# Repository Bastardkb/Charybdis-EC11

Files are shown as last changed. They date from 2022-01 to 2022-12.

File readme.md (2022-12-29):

# Charybdis EC11 PCB

EC11 PCB to be used in place of the trackball in the Charybdis keyboard.

`REV 1.2` is tested and working.

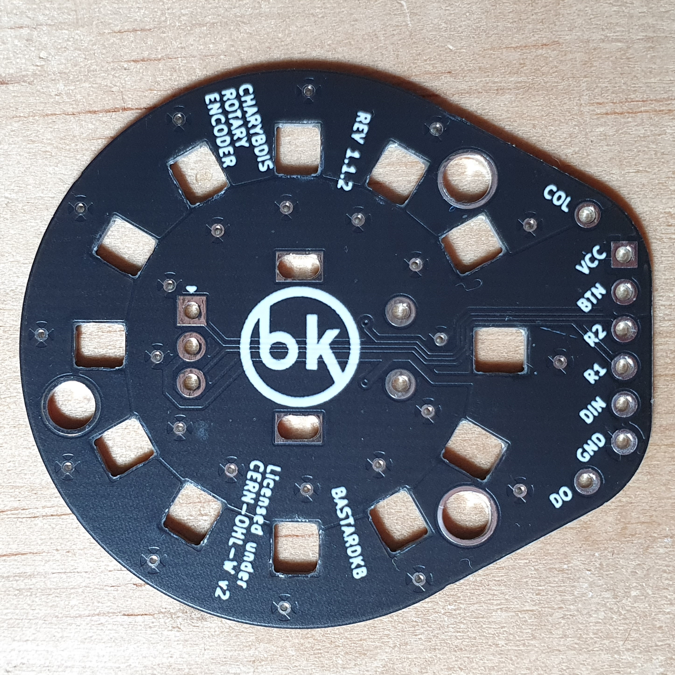
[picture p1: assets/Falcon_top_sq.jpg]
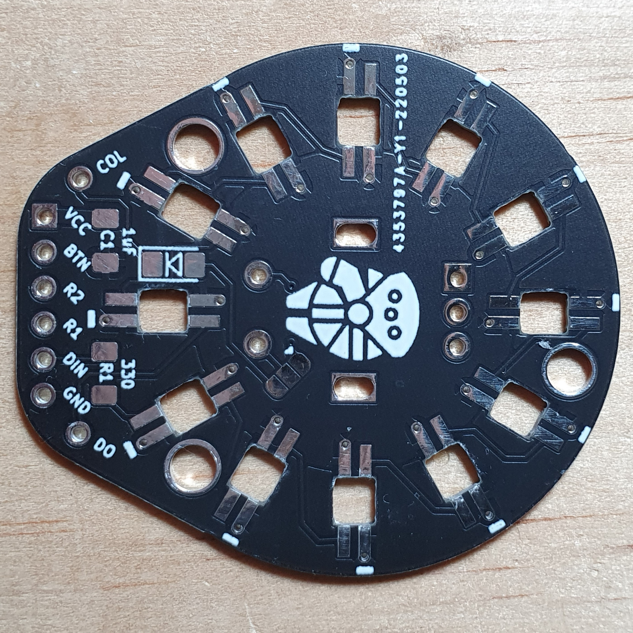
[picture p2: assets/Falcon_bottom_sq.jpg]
 

## EC11 Encoder
R1 and R2 pins are used for the encoder rotation pulses, these should be connected to unused pins on the microcontroller. The MOSI/MISO/SCLK/CS will be the most convenient - any two of these can be used.

For normal configuration of the pushbutton function with the Charybdis:
 - Bridge the 2 unmarked pads on the solder jumper
 - install a SOD-123 diode in the marked footprint
 - connect Col to a column and BTN to a row that corresponds with the missing thumb key matrix position

If your keyboard uses direct pin you will need to bridge the middle pad on the solder jumper with the marked pad. BTN should then be connected to a free GPIO pin on your microcontroller.

## LEDs
LEDs are optional. If not being used, VCC, GND, DIN, and DO can be ignored.

Otherwise:
- Install the capacitor and resistor on the marked footprints
- VCC and GND can be connected to wherever is the most convenient
- DIN and DO should be connected as part of the existing LED chain on the half - the suggested way to do this is to connect the DO from the PCB plate to the EC11 adapter DIN (instead of the thumb cluster), and the thumb cluster pcb DIN to the EC11 adapter DO

## Misc. Note
It should be possible to connect the adapter directly to the 6 pins of the trackball pin header on the shield for better aesthetics and modularity. However this would need custom matrix scanning code - to mix direct pin and switch matrix scanning, as well as a custom RGB LED driver to allow a second `RGB_DI` pin to be defined

## Parts you will need
### For every build

| Part name | Amount | Format  |
| --- | --- | --- |
| Diode, 1N4148 | 1 | SOD-123 |
| EC11 Rotary encoder | 1 | |
| Rotary encoder PCB* | 1 | |

*order the PCB using the latest *gerbers.zip from here: [Releases](https://github.com/Bastardkb/Charybdis-EC11/releases)

### Optional for LED functionality
| Part name | Amount per board | Format | Value  |
| --- | --- | --- | --- |
| SK6812-MINI-E | 12 | | |
| Capacitor | 1 | 1206 | 1uF |
| Resistor | 1 | 1206 | 330ohm |

## Knob
The knob work on the 20mm tall and 6mm diameter knurled stem.

Licensed under CERN-OHL-W v2.

Copyright Quentin Lebastard 2022.

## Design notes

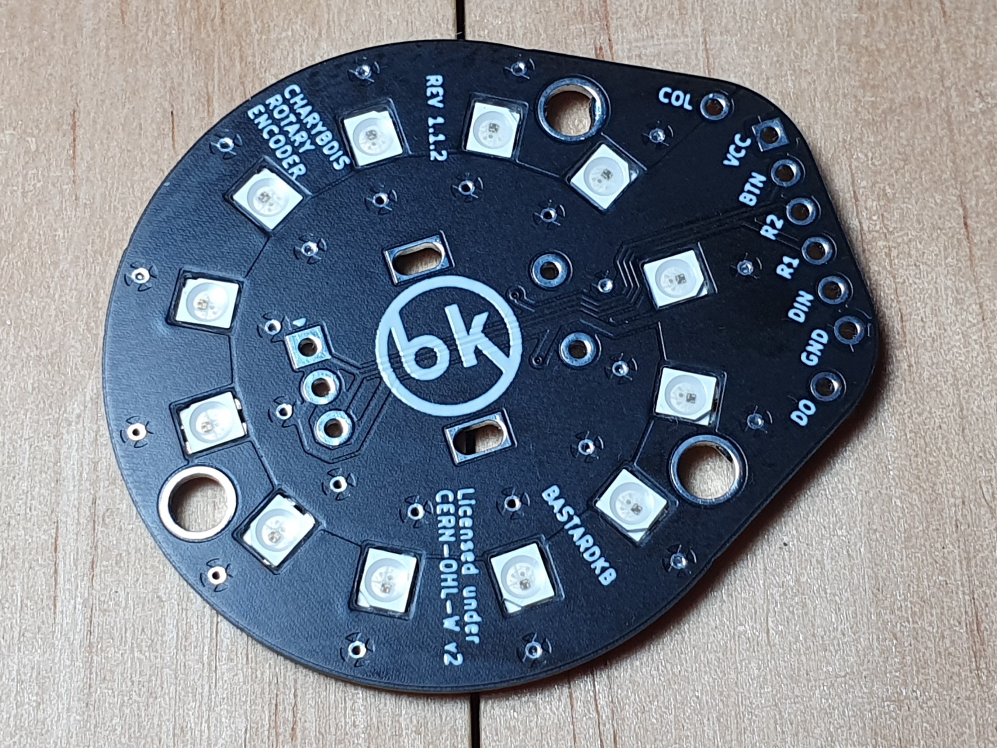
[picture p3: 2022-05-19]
assets/Falcon_top.jpg

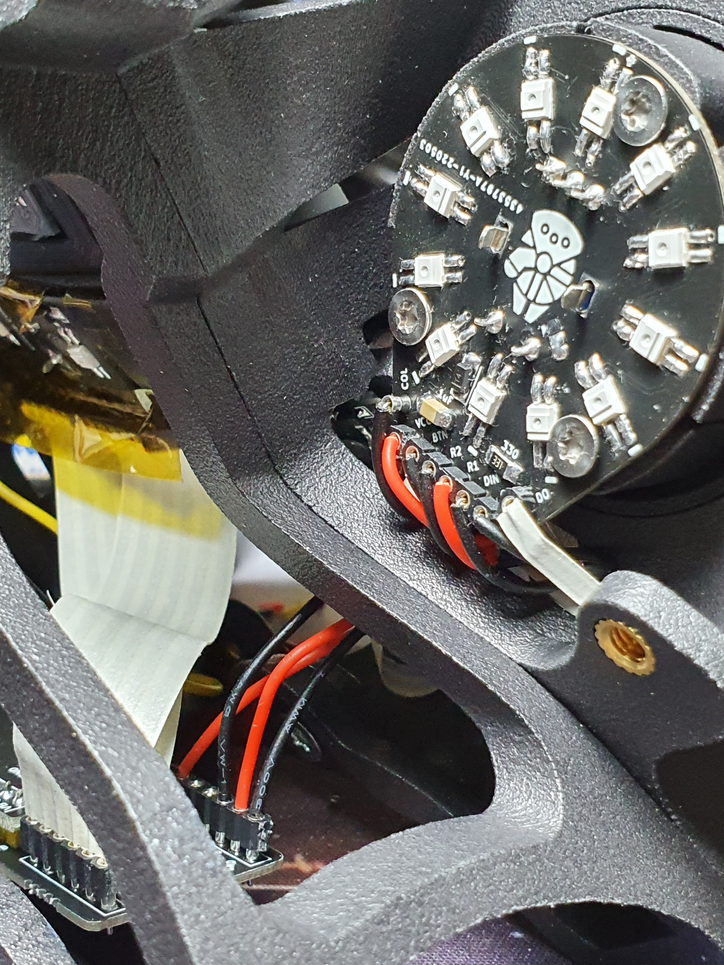
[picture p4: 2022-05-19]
assets/rough_connection_example.jpg

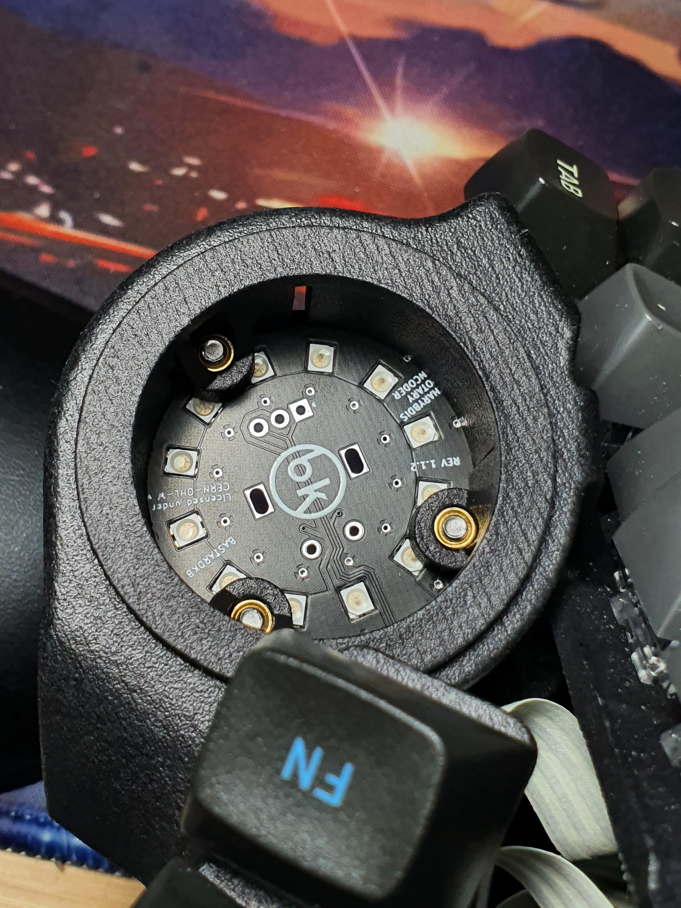
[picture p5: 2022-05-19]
assets/Partial_fit_example.jpg

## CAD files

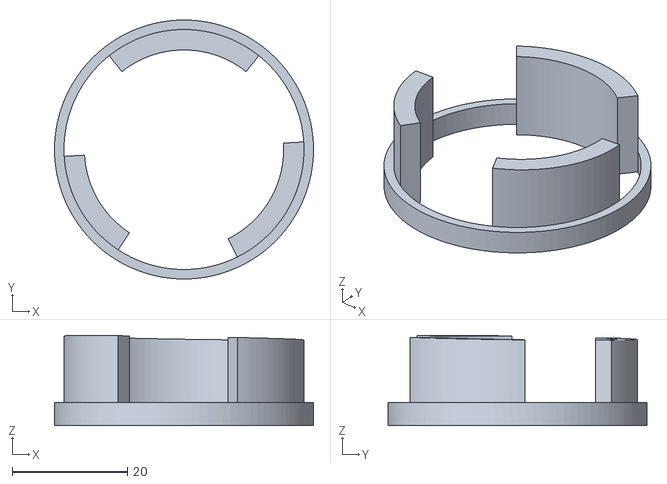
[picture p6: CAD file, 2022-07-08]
mechanical/bottom v7.stl
45.0 x 45.0 x 15.7

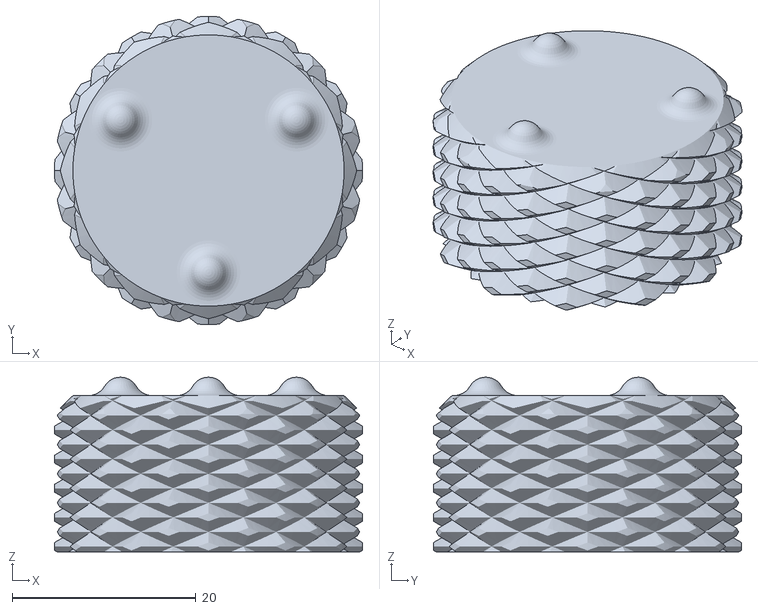
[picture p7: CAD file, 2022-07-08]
mechanical/Knob v5.stl
33.5 x 33.5 x 19.0

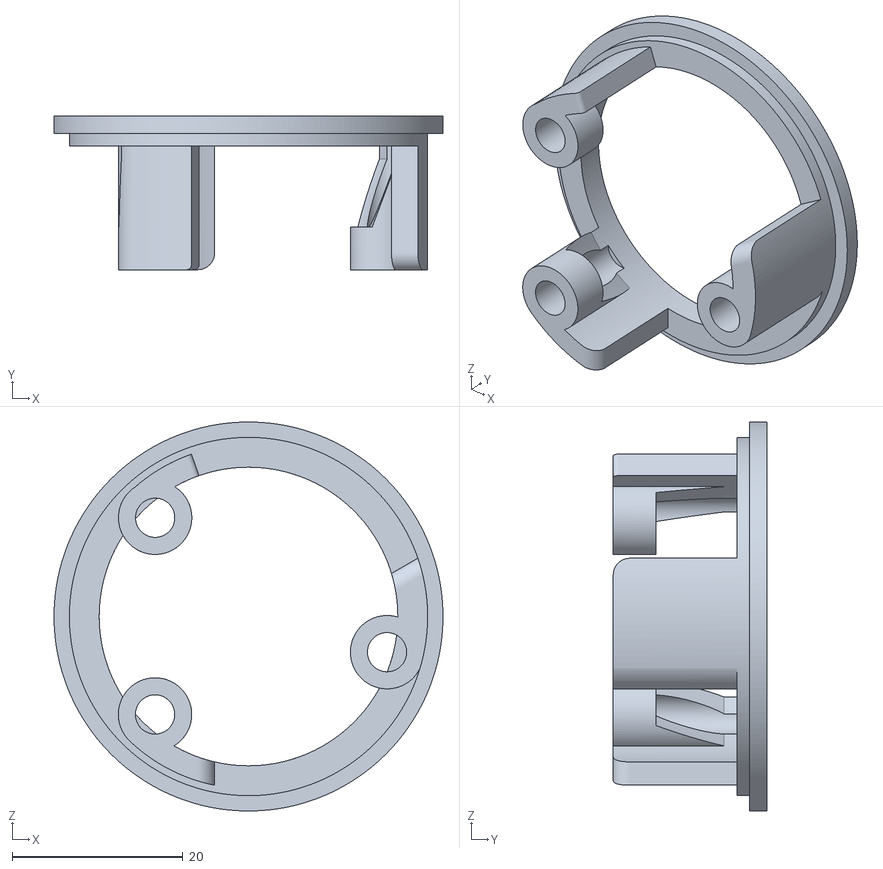
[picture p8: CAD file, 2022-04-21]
mechanical/top.stl
45.6 x 18.0 x 45.6

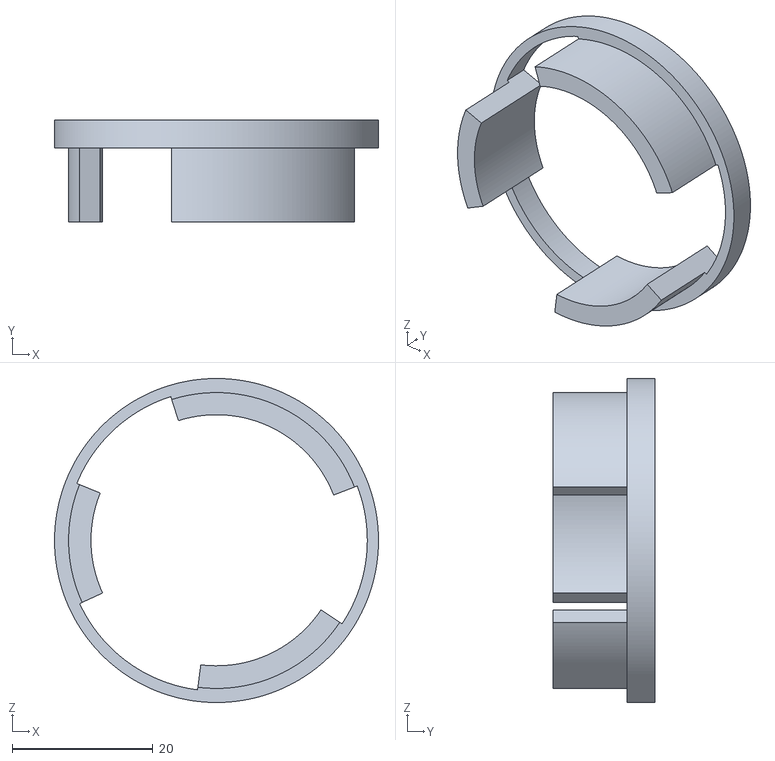
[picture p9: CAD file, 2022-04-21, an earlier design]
mechanical/bottom.stl
46.0 x 14.5 x 46.0

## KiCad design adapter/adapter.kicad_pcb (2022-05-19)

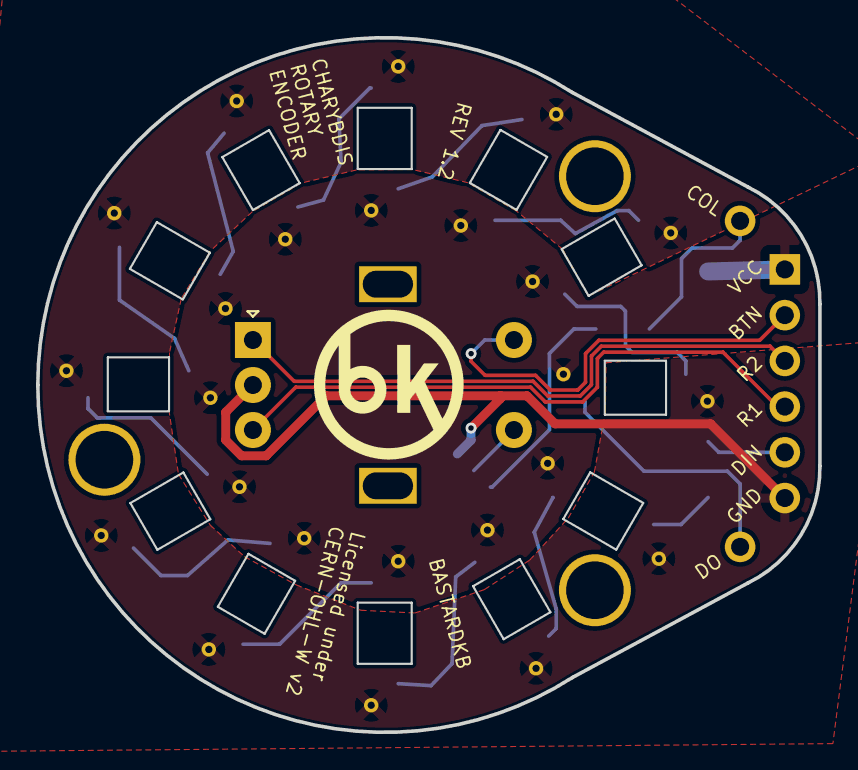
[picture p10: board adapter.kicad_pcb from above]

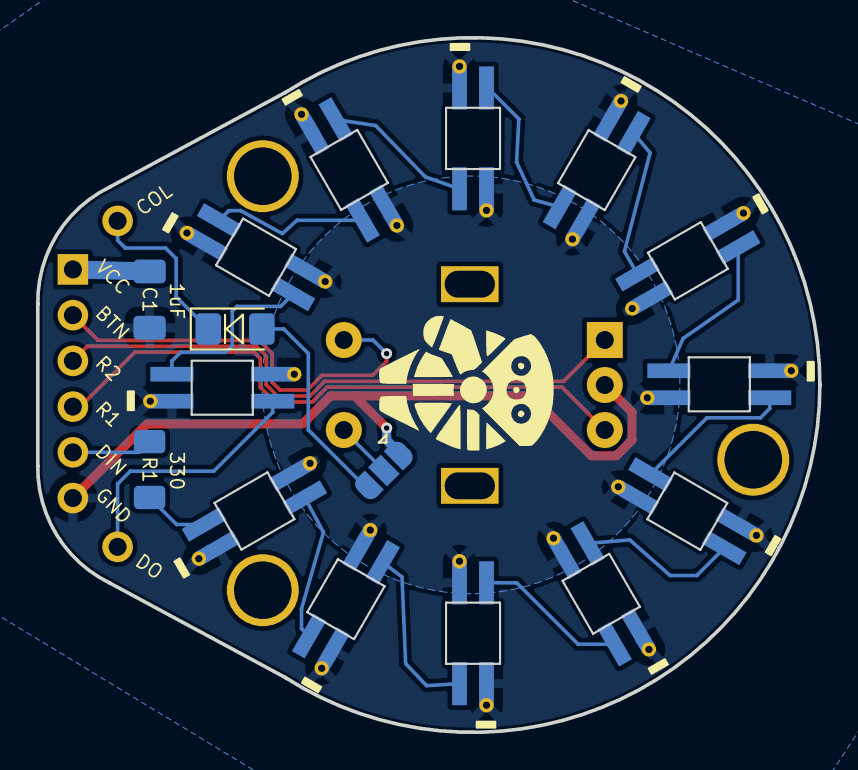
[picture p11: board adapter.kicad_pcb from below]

Board: 2 copper layers, 43.5 x 38.6 mm, 20 parts (16 on the bottom side), 22 nets.

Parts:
C1: 1u; C_1206_3216Metric_Pad1.33x1.80mm_HandSolder
D1, D2, D3, D4, D5, D6, D7, D8, D9, D10, D11, D12: SK6812MINI; YS-SK6812MINI-E
Dcol1: 1N4148W; D_1206_3216Metric_Pad1.42x1.75mm_HandSolder
J1: Conn_01x06_Female; 6_PinHeader
J2, J5: Conn_01x01_Female; 1_PinHeader
JP1: SolderJumper_3_Open; SolderJumper-3_P1.3mm_Open_RoundedPad1.0x1.5mm
R1: R; R_1206_3216Metric_Pad1.30x1.75mm_HandSolder
SW1: RotaryEncoder_Switch; RotaryEncoder_Alps_EC11E-Switch_Vertical_H20mm

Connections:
Col: Dcol1.1 (K), J2.1
DIN: J1.5, R1.2
DOUT: D12.1 (DOUT), J5.1
Gnd: C1.2, D1.2 (VSS), D2.2 (VSS), D3.2 (VSS), D4.2 (VSS), D5.2 (VSS), D6.2 (VSS), D7.2 (VSS), D8.2 (VSS), D9.2 (VSS), D10.2 (VSS), D11.2 (VSS), D12.2 (VSS), J1.6, JP1.1 (A), SW1.C
unnamed: D1.1 (DOUT), D2.3 (DIN)
unnamed: D1.3 (DIN), R1.1
unnamed: D2.1 (DOUT), D3.3 (DIN)
unnamed: D3.1 (DOUT), D4.3 (DIN)
unnamed: D4.1 (DOUT), D5.3 (DIN)
unnamed: D5.1 (DOUT), D6.3 (DIN)
unnamed: D6.1 (DOUT), D7.3 (DIN)
unnamed: D7.1 (DOUT), D8.3 (DIN)
unnamed: D8.1 (DOUT), D9.3 (DIN)
unnamed: D10.1 (DOUT), D11.3 (DIN)
unnamed: D9.1 (DOUT), D10.3 (DIN)
unnamed: D11.1 (DOUT), D12.3 (DIN)
unnamed: Dcol1.2 (A), JP1.3 (B)
unnamed: JP1.2 (C), SW1.S1
Vcc: C1.1, D1.4 (VDD), D2.4 (VDD), D3.4 (VDD), D4.4 (VDD), D5.4 (VDD), D6.4 (VDD), D7.4 (VDD), D8.4 (VDD), D9.4 (VDD), D10.4 (VDD), D11.4 (VDD), D12.4 (VDD), J1.1
button: J1.2, SW1.S2
r1: J1.4, SW1.B
r2: J1.3, SW1.A

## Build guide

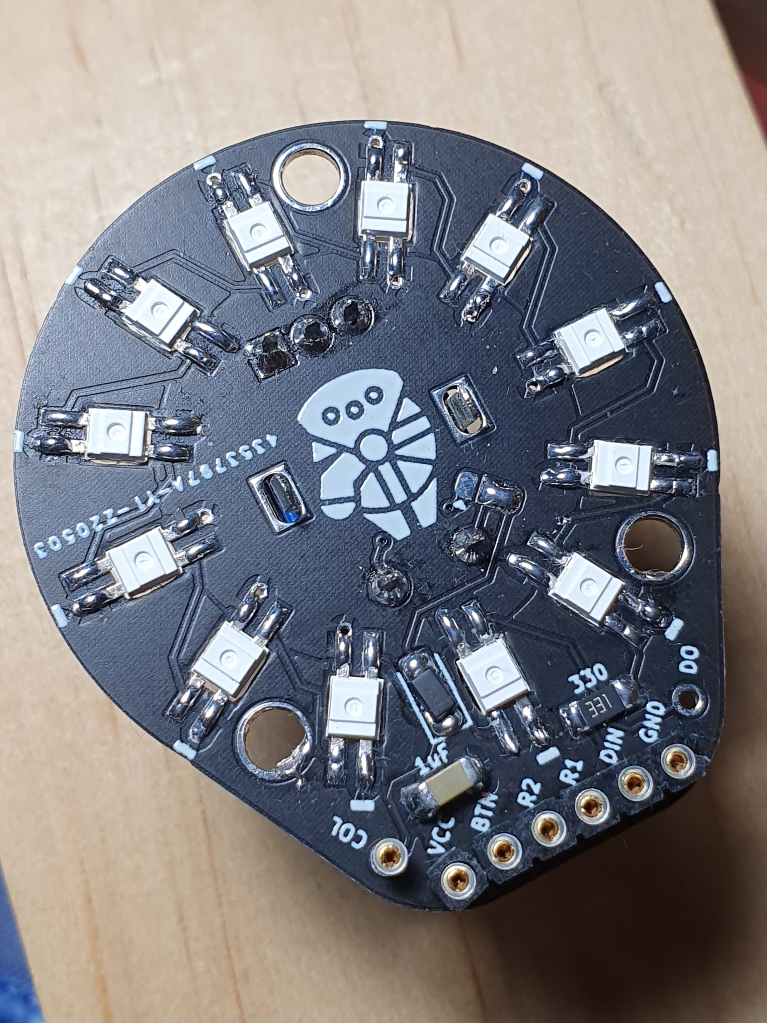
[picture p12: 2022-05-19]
assets/Falcon_bottom_soldered2.jpg

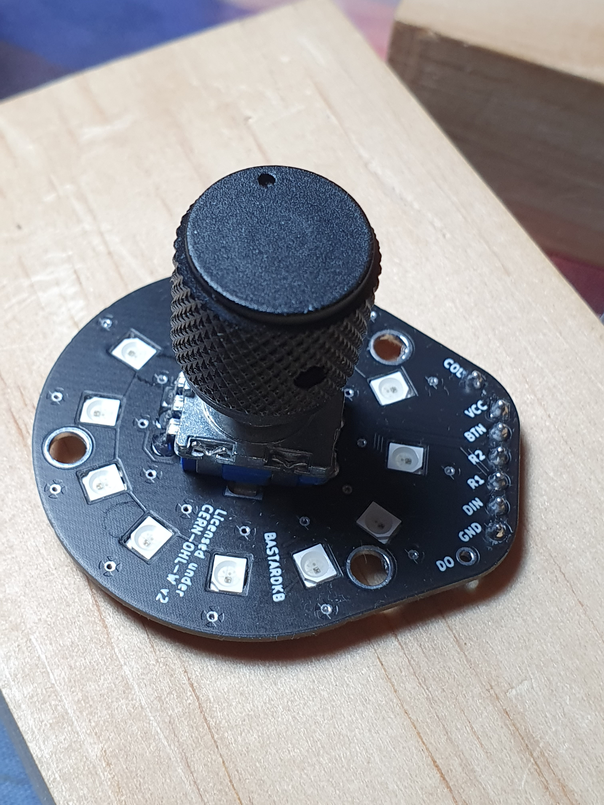
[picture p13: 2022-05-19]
assets/Falcon_top_soldered.jpg

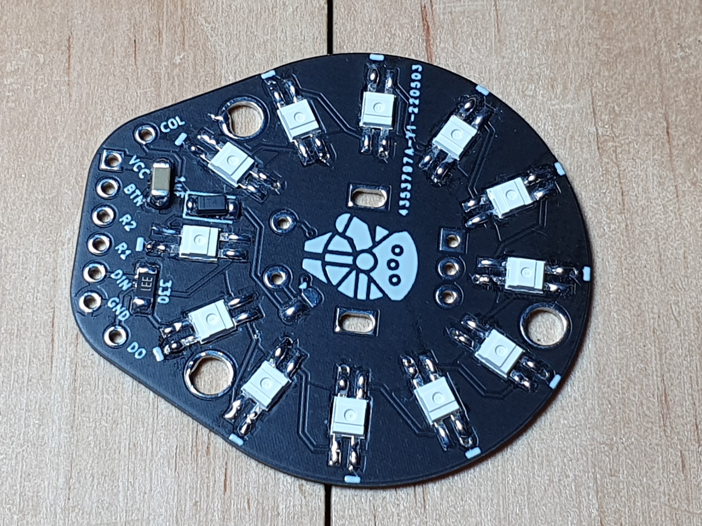
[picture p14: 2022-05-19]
assets/Falcon_bottom_soldered1.jpg

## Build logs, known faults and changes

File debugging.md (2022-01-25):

This is the chain of communication with the Blackpillboard until the USB part everything is on your host.

```
[VSCode + Cortex Debug Extension] <-(GDB Server)-> [OpenOCD] <-(USB)-> [STLink] <-(SWD)-> [STM32F411]
```

**You need:**

* `VSCode` with:
  * Cortex-Debug Extension 
  * Cortex-Debug Device Support Support Pack STM32F4
  * **(1)** A working `.vscode/launch.json` config that is configured for QMK and OpenOCD in the root of QMK folder
  * Optional a `.vscode/tasks.json` to build your firmware on every debug launch
* GCC ARM toolchain to supply `arm-none-eabi-gdb` (or use `gdb-multiarch`) and `arm-none-eabi-objdump`
* `OpenOCD` which communicates with the STLink and spans an GDB server that Cortex-Debug attaches to
* Working SWD connection from STLink to the STM32F411 debug Header 
  * Best to Google for the pinout of STLink V2, double check the connections this is likely to fail
* **(2)** Firmware in `ELF` format with debug symbols, `Og` optimization at max and without link time optimizations aka. `LTO`

**VSCode**

**(1) `launch.json`**

```json
{
    "version": "0.2.0",
    "configurations": [
        {
            "type": "cortex-debug",
            "servertype": "openocd",
            "interface": "swd",
            "request": "launch",
            "name": "Debug launch Blackpill STLink",
            "cwd": "${workspaceRoot}",
            "executable": ".build/karlk90_yaemk_koy.elf", /* Change this to your keyboard */
            "device": "STM32F411CE", /* Gives access to peripherals in Debugger view */
            "configFiles": [
                "/usr/share/openocd/scripts/board/st_nucleo_f4.cfg" /* Change this to the path of st_nucleo_f4.cfg */
            ],
            "runToEntryPoint": "main", /* Stops at the main function on entry */
            "rtos": "ChibiOS", /* Provides debugging of threads */
            "armToolchainPath": "/usr/bin/", /* Change this to the path of your GCC ARM toolchain */
            "gdbPath": "gdb-multiarch", /* Change this to the path of an ARM capable GDB e.g. arm-none-eabi-gdb */
            "preLaunchTask": "make keyboard" /* Run this task before every  */,
        }
    ]
}
```

**`tasks.json`**

```json
{
    "version": "2.0.0",
    "tasks": [
        {
            "label": "make keyboard",
            "type": "shell",
            "command": "make karlk90/yaemk:koy -j 12" /* Change this to your keyboard */
        },
    ]
}
```

**ELF with Debug capabilities**

**rules.mk**

```
LTO_ENABLE =   no
EXTRAFLAGS += -Og -gdwarf-4
ALLOW_WARNINGS =   yes
```

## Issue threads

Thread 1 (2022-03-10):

fixes

bstiq, 2022-03-10:
- [ ] switch led footprints to the other side
- [ ] switch r and c to the other side
- [ ] fix led footprints (in and out are reversed)
- [ ] add a dout pin

bstiq, 2022-05-19:
Done by @casuanoob . tysm !

Closed 2022-05-19.

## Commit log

2022-01-26 routing, add R C
    [adapter.kicad_pcb, adapter.kicad_sch]
2022-01-28 add screw holes
    [adapter.kicad_pcb]
2022-02-17 holes fix
    [adapter.kicad_pcb]
2022-04-18 complete reroute
    - routing changed to fix din/dout paths
    - added dout header
    - renamed rgb header to din
    - moved SMT components to bottom side
    - changed silkscreen to rev 1.1
    [adapter.kicad_pcb, adapter.kicad_sch]
2022-04-18 complete reroute
    [adapter-B_Cu.gbl, adapter-B_Mask.gbs, adapter-B_Paste.gbp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]
2022-04-18 fixing drc flags
    [adapter.kicad_pcb]
2022-04-18 fixing drc violations
    [adapter-B_Cu.gbl, adapter-B_Mask.gbs, adapter-B_Paste.gbp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]
2022-04-18 change vcc zone clearance
    [adapter.kicad_pcb]
2022-04-21 added row/col pin headers and jumpers for sw1 sw2
    Bodging the ec11 sw1 and sw2 pins to a free spot in the thumb cluster matrix would allow the pushbutton function to be mapped without needing a custom matrix.c code. Diode footprint added to support 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
    Jumpers added to allow selection between direct pin and matrix implementation
    [adapter.kicad_pcb]
2022-04-21 update extra library footprints
2022-04-21 add mechanical files
    [bottom.stl, top.stl]
2022-04-21 rearranged pins and reroute
    reverted BK logo to silkscreen
    [adapter.kicad_pcb, adapter.kicad_sch]
2022-04-25 flip LEDs to correct orientation
    [adapter.kicad_pcb, adapter.kicad_sch]
2022-04-25 added power flags to resolve erc error
    [adapter.kicad_sch]
2022-05-02 cleaned up extraneous gerber files that I accidentally added in a prior commit
    [adapter-B_Cu.gbl, adapter-B_Cu.gbr, adapter-B_Mask.gbr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]
2022-05-19 cleanup for 1.2 release
    [adapter-B_Cu.gbl, adapter-B_Mask.gbs, adapter-B_Paste.gbp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]
2022-06-26 Angled bottom so knob is centered
    [bottom v7.stl]
2022-06-26 Added two knobs
    [Knob v5.stl, Large_Knob.stl]
2022-07-04 Removed large knob
    [Large_Knob.stl]
2022-11-19 Adding materials to the readme, in shopping list form.

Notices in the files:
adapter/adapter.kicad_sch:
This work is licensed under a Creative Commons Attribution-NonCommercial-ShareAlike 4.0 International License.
